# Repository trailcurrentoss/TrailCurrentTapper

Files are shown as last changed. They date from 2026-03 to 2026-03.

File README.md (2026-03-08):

# TrailCurrent Tapper

Eight-button control panel that sends device commands and brightness control over a CAN bus interface with OTA firmware update capability. Part of the [TrailCurrent](https://trailcurrent.com) open-source vehicle platform.

## Hardware Overview

- **Microcontroller:** ESP32 (WROOM32)
- **Function:** Physical button panel for CAN bus device control
- **Key Features:**
  - 8 momentary buttons with LED backlights
  - Short press: toggle device on/off
  - Long press (hold 700ms+): brightness adjustment (0-255)
  - CAN bus communication at 500 kbps
  - Over-the-air (OTA) firmware updates via WiFi
  - LED state feedback from CAN bus
  - FreeCAD enclosure design

## Hardware Requirements

### Components

- **Microcontroller:** ESP32 development board
- **CAN Transceiver:** Vehicle CAN bus interface (TX: GPIO 15, RX: GPIO 13)

### Pin Connections

**Buttons (INPUT_PULLUP):**

| GPIO | Function |
|---|---|
| 34 | Button 1 |
| 25 | Button 2 |
| 27 | Button 3 |
| 12 | Button 4 |
| 16 | Button 5 |
| 22 | Button 6 |
| 21 | Button 7 |
| 18 | Button 8 |

**LED Backlights (OUTPUT):**

| GPIO | Function |
|---|---|
| 32 | LED 1 |
| 33 | LED 2 |
| 26 | LED 3 |
| 14 | LED 4 |
| 4 | LED 5 |
| 23 | LED 6 |
| 19 | LED 7 |
| 17 | LED 8 |

### KiCAD Library Dependencies

This project uses the consolidated [TrailCurrentKiCADLibraries](https://github.com/trailcurrentoss/TrailCurrentKiCADLibraries).

**Setup:**

```bash
# Clone the library
git clone git@github.com:trailcurrentoss/TrailCurrentKiCADLibraries.git

# Set environment variables (add to ~/.bashrc or ~/.zshrc)
export TRAILCURRENT_SYMBOL_DIR="/path/to/TrailCurrentKiCADLibraries/symbols"
export TRAILCURRENT_FOOTPRINT_DIR="/path/to/TrailCurrentKiCADLibraries/footprints"
export TRAILCURRENT_3DMODEL_DIR="/path/to/TrailCurrentKiCADLibraries/3d_models"
```

See [KICAD_ENVIRONMENT_SETUP.md](https://github.com/trailcurrentoss/TrailCurrentKiCADLibraries/blob/main/KICAD_ENVIRONMENT_SETUP.md) in the library repository for detailed setup instructions.

## Opening the Project

1. **Set up environment variables** (see Library Dependencies above)
2. **Open KiCAD:**
   ```bash
   kicad EDA/trailcurrent-tapper.kicad_pro
   ```
3. **Verify libraries load** - All symbol and footprint libraries should resolve without errors
4. **View 3D models** - Open PCB and press `Alt+3` to view the 3D visualization

## Firmware

See `src/` directory for PlatformIO-based firmware.

**Setup:**
```bash
# Install PlatformIO (if not already installed)
pip install platformio

# Build firmware
pio run

# Upload to board (serial)
pio run -t upload

# Upload via OTA (after initial flash)
pio run -t upload --upload-port esp32-DEVICE_ID
```

### Firmware Dependencies

This firmware depends on the following public libraries:

- **[OtaUpdateLibraryWROOM32](https://github.com/trailcurrentoss/OtaUpdateLibraryWROOM32)** (v0.0.1) - Over-the-air firmware update functionality
- **[TwaiTaskBasedLibraryWROOM32](https://github.com/trailcurrentoss/TwaiTaskBasedLibraryWROOM32)** (v0.0.1) - CAN bus communication interface

All dependencies are automatically resolved by PlatformIO during the build process.

### CAN Bus Protocol

**Transmit (Panel to Bus):**

| CAN ID | Bytes | Description |
|---|---|---|
| 0x18 | 1 | Button toggle (byte 0 = button index 0-7) |
| 0x15 | 2 | Brightness control (byte 0 = device index, byte 1 = brightness 0-255) |

**Receive (Bus to Panel):**

| CAN ID | Bytes | Description |
|---|---|---|
| 0x00 | 3 | OTA update trigger (MAC-based device targeting) |
| 0x1B | 8 | LED backlight state (1 byte per LED, 0=off, non-zero=on) |

### Button Behavior

- **Short press** (< 700ms): Sends toggle command on CAN ID 0x18
- **Long hold** (>= 700ms): Enters brightness mode, incrementing brightness every 100ms and sending on CAN ID 0x15
- **Release after hold**: Locks brightness at current value

## Manufacturing

- **PCB Files:** Ready for fabrication via standard PCB services (JLCPCB, OSH Park, etc.)
- **BOM Generation:** Export BOM from KiCAD schematic (Tools > Generate BOM)
- **Enclosure:** FreeCAD design included in `CAD/` directory
- **JLCPCB Assembly:** See [BOM_ASSEMBLY_WORKFLOW.md](https://github.com/trailcurrentoss/TrailCurrentKiCADLibraries/blob/main/BOM_ASSEMBLY_WORKFLOW.md) for detailed assembly workflow

## Project Structure

```
├── CAD/                          # FreeCAD enclosure design
├── EDA/                          # KiCAD hardware design files
│   ├── trailcurrent-tapper.kicad_pro
│   ├── trailcurrent-tapper.kicad_sch
│   └── trailcurrent-tapper.kicad_pcb
├── src/                          # Firmware source
│   ├── main.cpp                  # Button handling and CAN communication
│   ├── globals.h                 # LED pin definitions
│   ├── debug.h                   # Comprehensive debug macro system
│   ├── canHelper.h               # CAN bus configuration
│   └── Secrets.h.template        # WiFi credentials template
├── ARCHITECTURE_CORRECTED.md     # Architecture documentation
├── BUTTON_LED_FIX_SUMMARY.md     # Button/LED fix notes
├── platformio.ini                # Build configuration
└── partitions.csv                # ESP32 flash partition layout
```

## License

MIT License - See LICENSE file for details.

## Contributing

Improvements and contributions are welcome! Please submit issues or pull requests.

## Support

For questions about:
- **KiCAD setup:** See [KICAD_ENVIRONMENT_SETUP.md](https://github.com/trailcurrentoss/TrailCurrentKiCADLibraries/blob/main/KICAD_ENVIRONMENT_SETUP.md)
- **Assembly workflow:** See [BOM_ASSEMBLY_WORKFLOW.md](https://github.com/trailcurrentoss/TrailCurrentKiCADLibraries/blob/main/BOM_ASSEMBLY_WORKFLOW.md)

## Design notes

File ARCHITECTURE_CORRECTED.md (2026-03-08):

# Button/LED Architecture - Corrected

## Understanding the Multi-Panel System

The TrailCurrent Tapper operates in a **coordinated multi-panel environment** where multiple panels share the same CAN bus. Each panel can control lights on other panels, so LED state must be **synchronized via CAN** rather than controlled locally.

---

## Complete Message Flow

### 1️⃣ Button Press Event
```
Physical Button 1 Pressed
        ↓
while button held, every 200ms:
        ↓
send CAN ID 0x18, data[0]=0 (button index 0)
        ↓
Serial output: "[BTN] Button 1 pressed - CAN message sent"
```

### 2️⃣ External Controller Processing
```
Some device on CAN bus receives CAN ID 0x18
        ↓
Decides: "Button 1 pressed, toggle light 1"
        ↓
Updates its light state database
        ↓
Broadcasts new light state via CAN ID 0x1B
```

### 3️⃣ All Panels Update Lights
```
All panels (including this one) receive:
CAN ID 0x1B, data[0-7] = [light1_state, light2_state, ..., light8_state]
        ↓
Each panel updates its LED backlights
        ↓
Serial output: "[LED] Backlight states: 255,0,255,0,255,0,255,0"
```

### 4️⃣ Visual Feedback
```
LED backlights now show the CURRENT state from CAN bus
        ↓
If another panel turned light 1 on, this panel sees it too
        ↓
All panels always agree on the current state
```

---

## CAN Message Protocol

### Button Press Message (ID 0x18)
```
Identifier: 0x18 (24 decimal)
Data Length: 1 byte
Data Format: [button_index]
  - button_index = 0-7 (for buttons 1-8)

Example: Button 3 pressed
  ID: 0x18
  Data: [2]  (index 2 = button 3)
```

### LED State Broadcast (ID 0x1B)
```
Identifier: 0x1B (27 decimal)
Data Length: 8 bytes
Data Format: [led1, led2, led3, led4, led5, led6, led7, led8]
  - led_X = 0x00 (OFF) or 0xFF (ON) or any value > 0

Example: Lights 1, 3, 5, 7 are ON; 2, 4, 6, 8 are OFF
  ID: 0x1B
  Data: [0xFF, 0x00, 0xFF, 0x00, 0xFF, 0x00, 0xFF, 0x00]
```

---

## Code Implementation

### Button Handling (main.cpp loop)
```cpp
// HANDLE BTN01
if (digitalRead(BTN1_PIN) == LOW) {
  if ((millis() - btn01DebounceTime) > debounceDelay) {
    btn01DebounceTime = millis();
    send_message(0);  // Send button 1 (index 0)
  }
}
```
- Checks if button is pressed (LOW)
- Respects 200ms debounce delay
- Sends message every 200ms while button held
- No local LED toggle - just sends button press

### LED Receive (onCanRx callback)
```cpp
else if (msg.identifier == 0x1B) {
  // Expected: 8 bytes of LED data
  if (msg.data_length_code >= 8) {
    // Update LED backlights based on received state
    digitalWrite(LED1_PIN, msg.data[0] > 0 ? HIGH : LOW);
    digitalWrite(LED2_PIN, msg.data[1] > 0 ? HIGH : LOW);
    // ... (all 8 LEDs)
  }
}
```
- Only processes messages with ID 0x1B
- Updates all 8 LED GPIO pins based on received data
- No local state tracking - LEDs mirror CAN bus state

---

## Why This Architecture?

### Problem: Multiple Panels on Same Bus
- Panel A might control light 1
- Panel B might also control light 1
- What's the actual state of light 1?

### Solution: Single Source of Truth
- **The CAN bus is the source of truth**
- One device (or system) decides light states
- All devices receive the same state broadcast
- All devices display the same backlight status
- No conflicts, no confusion

### Benefits
✅ **Synchronized**: All panels always show correct state
✅ **Coordinated**: Multiple panels don't conflict
✅ **Simple**: Buttons just send press events
✅ **Scalable**: Works with any number of panels
✅ **Reliable**: State is explicit, not inferred

---

## Testing the System

### What You Should See

**When Button 1 is Pressed:**
```
[BTN] Button 1 pressed - CAN message sent
```
(Repeats every 200ms while button is held)

**When LED State is Broadcast:**
```
[LED] Backlight states: 255,0,255,0,255,0,255,0
```
(Shows all 8 LED values received from CAN bus)

**Expected Behavior:**
1. Press button 1 → see button message
2. External system (controller) receives it and broadcasts new state
3. This panel receives new LED state and updates backlights
4. All panels update backlights

### If It's Not Working

**Symptoms: Button press but LED doesn't update**
- Issue: Button message being sent but controller not responding
- Check: Is there a device on CAN bus listening to ID 0x18?
- Check: Is that device sending back LED state on ID 0x1B?

**Symptoms: LED updates but wrong lights**
- Issue: CAN message data[X] mapping is wrong
- Check: Verify LED data byte order matches your hardware
- Check: Verify LED GPIO pins are correct

**Symptoms: Multiple lights turning on unexpectedly**
- Issue: Button 1 press was causing multiple buttons to trigger
- Check: GPIO pin definitions (BTN1_PIN, etc.)
- Check: Button INPUT_PULLUP configuration
- Check: Debounce timing

---

## Original vs New Architecture

### Original (Polling-Based)
- Raw TWAI driver in canHelper.h
- CAN polling in main loop (every iteration)
- Synchronous message reception
- Filter: Only accept ID 0x1B messages
- No OTA support

### New (Callback-Based with OTA)
- TwaiTaskBased library (FreeRTOS tasks)
- Asynchronous callbacks for RX/TX
- Tasks handle CAN in background
- Accept-all filter (process all IDs in callbacks)
- OTA support via CAN ID 0x0 trigger
- Variadic debug macros

**The Button/LED logic remains the same**, just using new library:
- Buttons still send ID 0x18
- LEDs still respond to ID 0x1B
- Same message format, same behavior

---

## Multi-Device Example

### Scenario: 2 Panels on Same Bus

```
Panel A (this device):         Panel B (other device):
├─ Button 1                    ├─ Button 1
├─ Button 2                    ├─ Button 2
├─ LED 1-8 backlights          ├─ LED 1-8 backlights
└─ CAN bus                     └─ CAN bus
         │                            │
         └────────────────────────────┘
                (shared CAN)

Scenario: User presses Button 1 on Panel B
1. Panel B sends: CAN ID 0x18, data[0]=0
2. Central controller receives and toggles light 1
3. Controller broadcasts: CAN ID 0x1B, data=[255,0,0,0,0,0,0,0]
4. Panel A receives and updates: LED1=ON, LED2-8=OFF
5. Panel B receives and updates: LED1=ON, LED2-8=OFF
6. Both panels show same state ✅
```

---

## Configuration Reference

### GPIO Pins (globals.h)
```cpp
LED1_PIN = 32,  LED2_PIN = 33,  LED3_PIN = 26,  LED4_PIN = 14
LED5_PIN = 4,   LED6_PIN = 23,  LED7_PIN = 19,  LED8_PIN = 17

BTN1_PIN = 34,  BTN2_PIN = 25,  BTN3_PIN = 27,  BTN4_PIN = 12
BTN5_PIN = 16,  BTN6_PIN = 22,  BTN7_PIN = 21,  BTN8_PIN = 18
```

### CAN Settings (main.cpp)
```cpp
CAN_TX = GPIO 15
CAN_RX = GPIO 13
Baudrate = 500 kbps
Filter = Accept all messages
```

### Debounce Timing (main.cpp)
```cpp
debounceDelay = 200ms  // Minimum time between button messages
```

---

## Summary

**The system works as a coordinated CAN bus network:**
- Buttons send requests (button press events)
- A controller processes requests (toggles lights, makes decisions)
- Controller broadcasts state (all lights current status)
- All panels display state (LED backlights show current state)

**This ensures all panels always agree on the current light state**, regardless of which panel's button was pressed.

**Files Modified:**
- `src/main.cpp` - Simplified button/LED logic to match original architecture
- `src/globals.h` - Cleaned up and organized LED/button pins

**Date Corrected:** 2026-02-10

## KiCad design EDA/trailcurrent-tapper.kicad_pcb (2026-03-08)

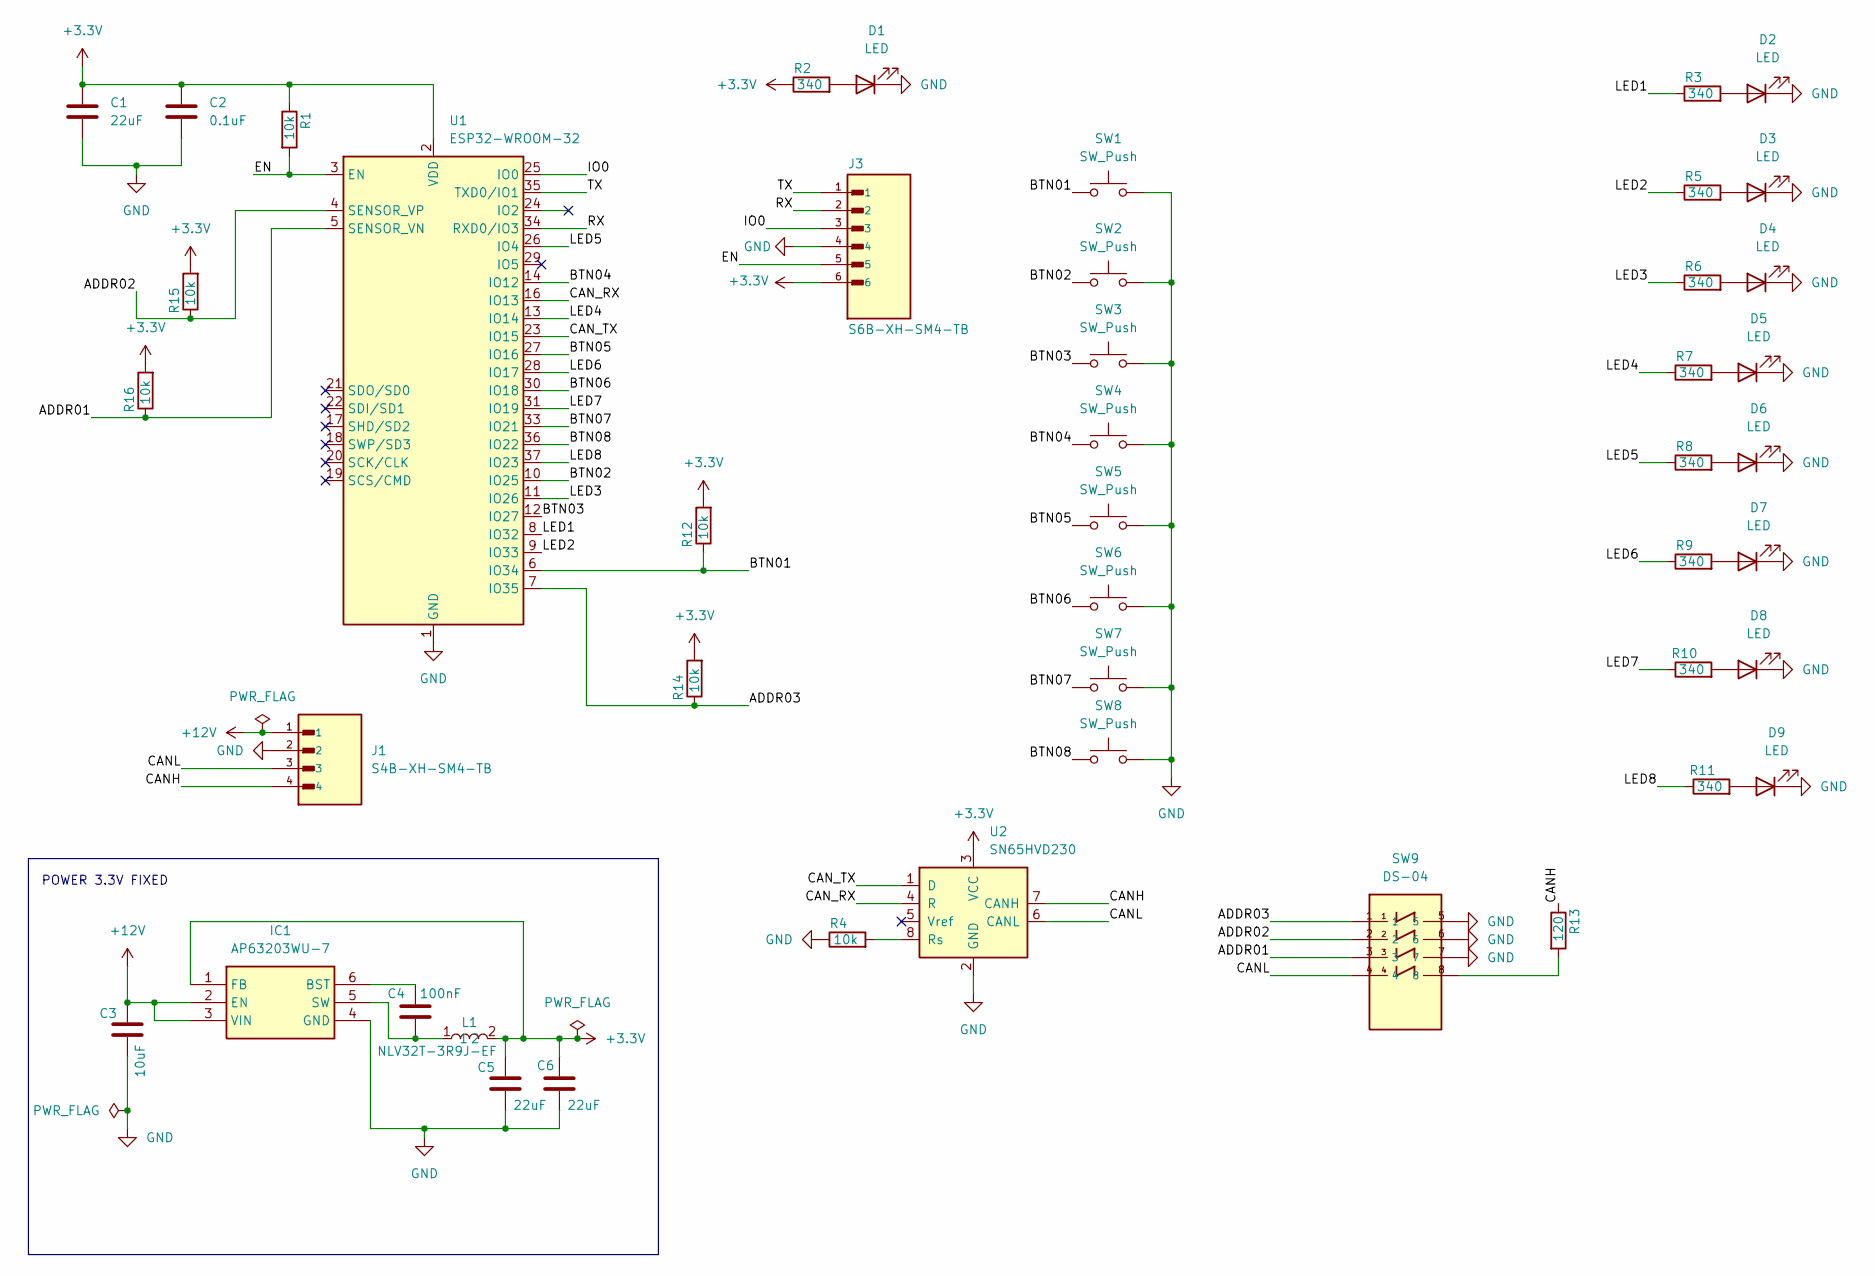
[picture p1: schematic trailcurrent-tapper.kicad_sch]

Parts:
C1, C5, C6: 22uF; C_1206_3216Metric_Pad1.33x1.80mm_HandSolder
C2: 0.1uF; C_1206_3216Metric_Pad1.33x1.80mm_HandSolder
C3: 10uF; C_1206_3216Metric
C4: 100nF; C_1206_3216Metric
D1, D2, D3, D4, D5, D6, D7, D8, D9: LED; LED_1206_3216Metric_Pad1.42x1.75mm_HandSolder
IC1: AP63203WU-7; AP63203WU7; Mouser Part Number 621-AP63203WU-7
J1: S4B-XH-SM4-TB; JST_S4B-XH-SM4-TB; LCSC Part C161861
J3: S6B-XH-SM4-TB; JST_S6B-XH-SM4-TB; LCSC Part C191914
L1: NLV32T-3R9J-EF; Manufacturer_Part_Number NLV32T-3R9J-EF; Mouser Part Number 810-NLV32T3R9JEF
R1, R4, R12, R14, R15, R16: 10k; R_1206_3216Metric_Pad1.30x1.75mm_HandSolder
R2, R3, R5, R6, R7, R8, R9, R10, R11: 340; R_1206_3216Metric_Pad1.30x1.75mm_HandSolder
R13: 120; R_1206_3216Metric_Pad1.30x1.75mm_HandSolder
SW1, SW2, SW3, SW4, SW5, SW6, SW7, SW8: SW_Push; SW_PUSH_6mm
SW9: DS-04; Manufacturer_Part_Number DS-04
U1: ESP32-WROOM-32; ESP32-WROOM-32U
U2: SN65HVD230; SOIC-8_3.9x4.9mm_P1.27mm

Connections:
+3.3V: C1.1, C2.1, C5.1, C6.1, IC1.1 (FB), J3.6, L1.2, R1.1, R2.1, R12.2, R14.2, R15.2, R16.2, U1.2 (VDD), U2.3 (VCC)
+12V: C3.1, IC1.2 (EN), IC1.3 (VIN), J1.1
/ADDR01: R16.1, SW9.3, U1.5 (SENSOR_VN)
/ADDR02: R15.1, SW9.2, U1.4 (SENSOR_VP)
/ADDR03: R14.1, SW9.1, U1.7 (IO35)
/BTN01: R12.1, SW1.1, U1.6 (IO34)
/BTN02: SW2.1, U1.10 (IO25)
/BTN03: SW3.1, U1.12 (IO27)
/BTN04: SW4.1, U1.14 (IO12)
/BTN05: SW5.1, U1.27 (IO16)
/BTN06: SW6.1, U1.30 (IO18)
/BTN07: SW7.1, U1.33 (IO21)
/BTN08: SW8.1, U1.36 (IO22)
/CANH: J1.4, R13.1, U2.7 (CANH)
/CANL: J1.3, SW9.4, U2.6 (CANL)
/CAN_RX: U1.16 (IO13), U2.4 (R)
/CAN_TX: U1.23 (IO15), U2.1 (D)
/EN: J3.5, R1.2, U1.3 (EN)
/IO0: J3.3, U1.25 (IO0)
/LED1: R3.1, U1.8 (IO32)
/LED2: R5.1, U1.9 (IO33)
/LED3: R6.1, U1.11 (IO26)
/LED4: R7.1, U1.13 (IO14)
/LED5: R8.1, U1.26 (IO4)
/LED6: R9.1, U1.28 (IO17)
/LED7: R10.1, U1.31 (IO19)
/LED8: R11.1, U1.37 (IO23)
/RX: J3.2, U1.34 (RXD0/IO3)
/TX: J3.1, U1.35 (TXD0/IO1)
GND: C1.2, C2.2, C3.2, C5.2, C6.2, D1.1 (K), D2.1 (K), D3.1 (K), D4.1 (K), D5.1 (K), D6.1 (K), D7.1 (K), D8.1 (K), D9.1 (K), IC1.4 (GND), J1.2, J3.4, R4.1, SW1.2, SW2.2, SW3.2, SW4.2, SW5.2, SW6.2, SW7.2, SW8.2, SW9.5, SW9.6, SW9.7, U1.1 (GND), U1.15 (GND), U1.38 (GND), U1.39 (GND), U2.2 (GND)
unnamed: D1.2 (A), R2.2
unnamed: D2.2 (A), R3.2
unnamed: D3.2 (A), R5.2
unnamed: D4.2 (A), R6.2
unnamed: D5.2 (A), R7.2
unnamed: D6.2 (A), R8.2
unnamed: D7.2 (A), R9.2
unnamed: D8.2 (A), R10.2
unnamed: D9.2 (A), R11.2
unnamed: C4.1, IC1.6 (BST)
unnamed: C4.2, IC1.5 (SW), L1.1
unnamed: R13.2, SW9.8
unnamed: R4.2, U2.8 (Rs)

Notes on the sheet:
POWER 3.3V FIXED

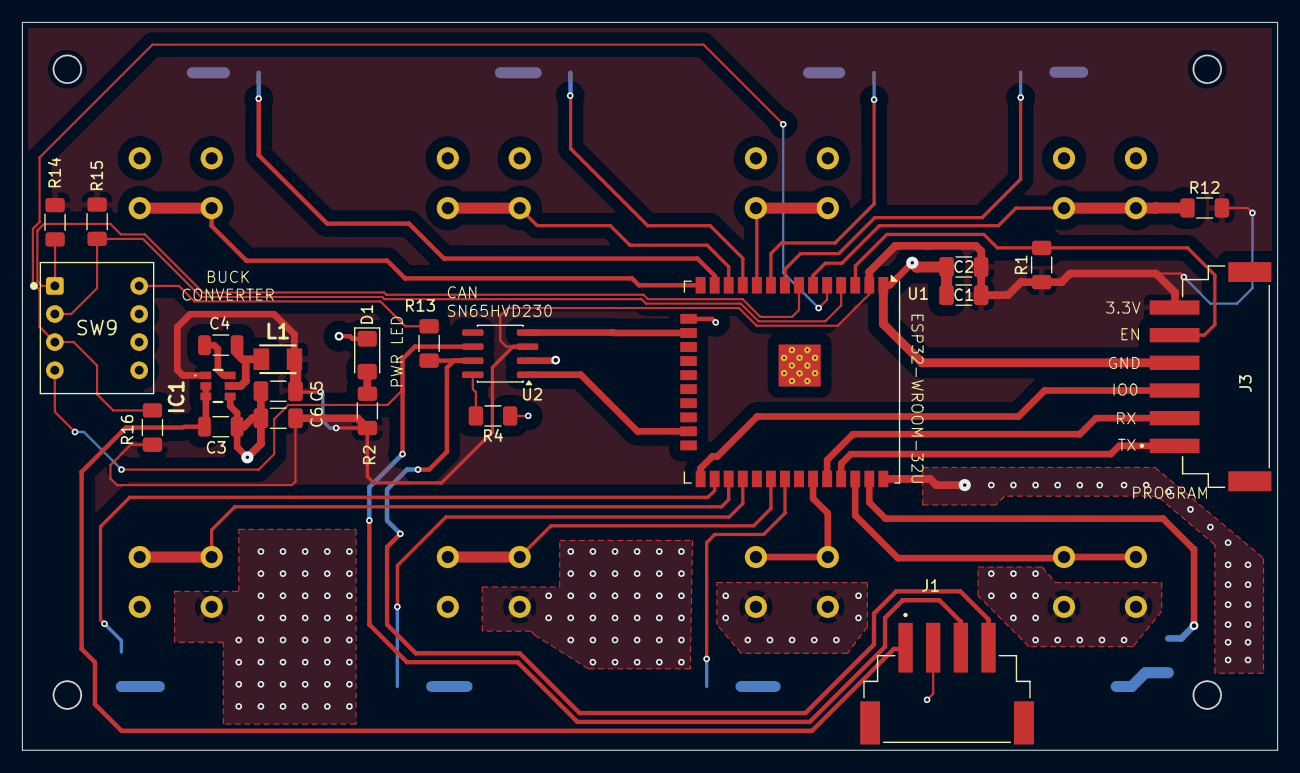
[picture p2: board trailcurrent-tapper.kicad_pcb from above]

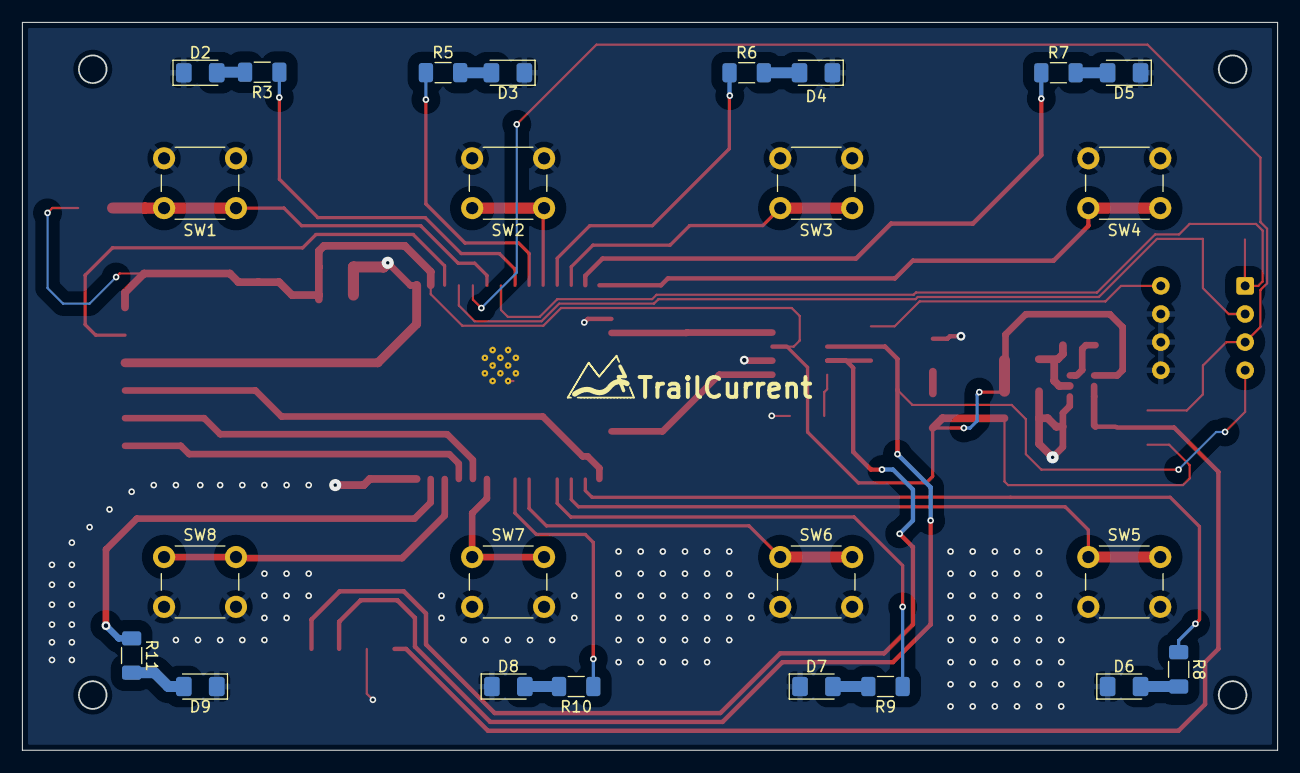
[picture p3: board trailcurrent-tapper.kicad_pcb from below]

Board: 2 copper layers, 113.4 x 65.8 mm, 48 parts (25 on the bottom side), 43 nets.

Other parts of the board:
LOGO: TrailCurrentLogo_Text
LOGO#2: TrailCurrentLogo_Icon

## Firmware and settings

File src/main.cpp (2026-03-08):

#include <Arduino.h>
#include <stdint.h>
#include <Preferences.h>
#include <TwaiTaskBased.h>
#include <OtaUpdate.h>
#include "globals.h"

// Button debounce timing
unsigned long btn01DebounceTime = 0;
unsigned long btn02DebounceTime = 0;
unsigned long btn03DebounceTime = 0;
unsigned long btn04DebounceTime = 0;
unsigned long btn05DebounceTime = 0;
unsigned long btn06DebounceTime = 0;
unsigned long btn07DebounceTime = 0;
unsigned long btn08DebounceTime = 0;
unsigned long debounceDelay = 200;

// Button state tracking for press-and-hold brightness control
unsigned long btn01PressStartTime = 0;
unsigned long btn02PressStartTime = 0;
unsigned long btn03PressStartTime = 0;
unsigned long btn04PressStartTime = 0;
unsigned long btn05PressStartTime = 0;
unsigned long btn06PressStartTime = 0;
unsigned long btn07PressStartTime = 0;
unsigned long btn08PressStartTime = 0;

bool btn01WasPressed = false;
bool btn02WasPressed = false;
bool btn03WasPressed = false;
bool btn04WasPressed = false;
bool btn05WasPressed = false;
bool btn06WasPressed = false;
bool btn07WasPressed = false;
bool btn08WasPressed = false;

bool btn01ToggleSent = false;
bool btn02ToggleSent = false;
bool btn03ToggleSent = false;
bool btn04ToggleSent = false;
bool btn05ToggleSent = false;
bool btn06ToggleSent = false;
bool btn07ToggleSent = false;
bool btn08ToggleSent = false;

bool btn01InBrightnessMode = false;
bool btn02InBrightnessMode = false;
bool btn03InBrightnessMode = false;
bool btn04InBrightnessMode = false;
bool btn05InBrightnessMode = false;
bool btn06InBrightnessMode = false;
bool btn07InBrightnessMode = false;
bool btn08InBrightnessMode = false;

uint8_t btn01Brightness = 0;
uint8_t btn02Brightness = 0;
uint8_t btn03Brightness = 0;
uint8_t btn04Brightness = 0;
uint8_t btn05Brightness = 0;
uint8_t btn06Brightness = 0;
uint8_t btn07Brightness = 0;
uint8_t btn08Brightness = 0;

unsigned long btn01LastBrightnessUpdate = 0;
unsigned long btn02LastBrightnessUpdate = 0;
unsigned long btn03LastBrightnessUpdate = 0;
unsigned long btn04LastBrightnessUpdate = 0;
unsigned long btn05LastBrightnessUpdate = 0;
unsigned long btn06LastBrightnessUpdate = 0;
unsigned long btn07LastBrightnessUpdate = 0;
unsigned long btn08LastBrightnessUpdate = 0;

// Timing constants for brightness control
const unsigned long HOLD_THRESHOLD = 700;        // 700ms to enter brightness mode
const unsigned long BRIGHTNESS_INCREMENT = 100;  // Update brightness every 100ms

// Button GPIO pins
#define BTN1_PIN 34
#define BTN2_PIN 25
#define BTN3_PIN 27
#define BTN4_PIN 12
#define BTN5_PIN 16
#define BTN6_PIN 22
#define BTN7_PIN 21
#define BTN8_PIN 18

// WiFi credential reception state (CAN ID 0x01 protocol)
bool wifiConfigInProgress = false;
uint8_t wifiSsidBuffer[33];       // Max 32 chars + null
uint8_t wifiPasswordBuffer[64];   // Max 63 chars + null
uint8_t wifiSsidLen = 0;          // Expected total SSID length
uint8_t wifiPasswordLen = 0;      // Expected total password length
uint8_t wifiSsidReceived = 0;     // Bytes received so far
uint8_t wifiPasswordReceived = 0;

// Create OTA update handler (3-minute timeout, 180000 ms)
// Credentials are loaded from NVS when OTA is triggered; empty here for getHostName() only
OtaUpdate otaUpdate(180000, "", "");

/**
 * Save WiFi credentials to NVS (Non-Volatile Storage)
 */
void saveWifiCredentials(const char* ssid, const char* password) {
  Preferences prefs;
  prefs.begin("wifi", false);  // read-write
  prefs.putString("ssid", ssid);
  prefs.putString("password", password);
  prefs.end();
  debugf("[WiFi] Credentials saved to NVS (SSID: %s)\n", ssid);
}

/**
 * Handle WiFi credential CAN messages (CAN ID 0x01)
 * Protocol uses data[0] as message type:
 *   0x01: Start - contains SSID/password lengths and chunk counts
 *   0x02: SSID chunk - chunk_index + up to 6 data bytes
 *   0x03: Password chunk - chunk_index + up to 6 data bytes
 *   0x04: End - XOR checksum for validation
 */
void handleWifiConfigMessage(const twai_message_t &msg) {
  uint8_t msgType = msg.data[0];

  switch (msgType) {
    case 0x01: {  // Start message
      wifiSsidLen = msg.data[1];
      wifiPasswordLen = msg.data[2];
      wifiSsidReceived = 0;
      wifiPasswordReceived = 0;
      memset(wifiSsidBuffer, 0, sizeof(wifiSsidBuffer));
      memset(wifiPasswordBuffer, 0, sizeof(wifiPasswordBuffer));
      wifiConfigInProgress = true;
      debugf("[WiFi] Config start: SSID len=%d, Password len=%d\n", wifiSsidLen, wifiPasswordLen);
      break;
    }

    case 0x02: {  // SSID chunk
      if (!wifiConfigInProgress) break;
      uint8_t dataBytes = msg.data_length_code - 2;
      uint8_t remaining = wifiSsidLen - wifiSsidReceived;
      if (dataBytes > remaining) dataBytes = remaining;
      if (wifiSsidReceived + dataBytes <= 32) {
        memcpy(wifiSsidBuffer + wifiSsidReceived, &msg.data[2], dataBytes);
        wifiSsidReceived += dataBytes;
      }
      break;
    }

    case 0x03: {  // Password chunk
      if (!wifiConfigInProgress) break;
      uint8_t dataBytes = msg.data_length_code - 2;
      uint8_t remaining = wifiPasswordLen - wifiPasswordReceived;
      if (dataBytes > remaining) dataBytes = remaining;
      if (wifiPasswordReceived + dataBytes <= 63) {
        memcpy(wifiPasswordBuffer + wifiPasswordReceived, &msg.data[2], dataBytes);
        wifiPasswordReceived += dataBytes;
      }
      break;
    }

    case 0x04: {  // End message with checksum
      if (!wifiConfigInProgress) break;
      wifiConfigInProgress = false;

      // Verify XOR checksum
      uint8_t checksum = 0;
      for (uint8_t i = 0; i < wifiSsidReceived; i++) checksum ^= wifiSsidBuffer[i];
      for (uint8_t i = 0; i < wifiPasswordReceived; i++) checksum ^= wifiPasswordBuffer[i];

      if (checksum == msg.data[1] && wifiSsidReceived == wifiSsidLen && wifiPasswordReceived == wifiPasswordLen) {
        wifiSsidBuffer[wifiSsidReceived] = '\0';
        wifiPasswordBuffer[wifiPasswordReceived] = '\0';
        saveWifiCredentials((const char*)wifiSsidBuffer, (const char*)wifiPasswordBuffer);
      } else {
        debugf("[WiFi] Config failed: checksum %s, SSID %d/%d bytes, Password %d/%d bytes\n",
               (checksum == msg.data[1]) ? "OK" : "MISMATCH",
               wifiSsidReceived, wifiSsidLen, wifiPasswordReceived, wifiPasswordLen);
      }
      break;
    }
  }
}

/**
 * CAN RX Callback - called when a CAN message is received
 * Handles three types of messages:
 *   - ID 0x0: OTA trigger (MAC-based targeting)
 *   - ID 0x01: WiFi credential configuration
 *   - ID 0x1B: LED control commands
 */
void onCanRx(const twai_message_t &msg) {
  // OTA trigger message (ID 0x0)
  if (msg.identifier == 0x0) {
    debugln("[OTA] CAN trigger received");

    // Extract target hostname from CAN data
    char updateForHostName[14];
    String currentHostName = otaUpdate.getHostName();

    // Format: esp32-XXXXXX where X is MAC address in hex
    sprintf(updateForHostName, "esp32-%02X%02X%02X",
            msg.data[0], msg.data[1], msg.data[2]);

    debugf("[OTA] Target hostname: %s\n", updateForHostName);
    debugf("[OTA] Current hostname: %s\n", currentHostName.c_str());

    // Check if this OTA trigger is for this device
    if (currentHostName.equals(updateForHostName)) {
      debugln("[OTA] Hostname matched - reading WiFi credentials from NVS");
      Preferences prefs;
      prefs.begin("wifi", true);  // read-only
      String ssid = prefs.getString("ssid", "");
      String password = prefs.getString("password", "");
      prefs.end();

      if (ssid.length() > 0 && password.length() > 0) {
        debugf("[OTA] Using stored WiFi credentials (SSID: %s)\n", ssid.c_str());
        OtaUpdate ota(180000, ssid.c_str(), password.c_str());
        ota.waitForOta();
        debugln("[OTA] OTA mode exited - resuming normal operation");
      } else {
        debugln("[OTA] ERROR: No WiFi credentials in NVS - cannot start OTA");
      }
    }
  }

  // WiFi credential configuration message (ID 0x01)
  else if (msg.identifier == 0x01) {
    handleWifiConfigMessage(msg);
  }

  // LED control message (ID 0x1B) - updates LED backlights to show current state
  else if (msg.identifier == 0x1B) {
    // Expected: 8 bytes of LED data (0 = OFF, non-zero = ON)
    if (msg.data_length_code >= 8) {
      debugln("[LED] LED state update received");

      // Update LED backlights based on received state
      digitalWrite(LED1_PIN, msg.data[0] > 0 ? HIGH : LOW);
      digitalWrite(LED2_PIN, msg.data[1] > 0 ? HIGH : LOW);
      digitalWrite(LED3_PIN, msg.data[2] > 0 ? HIGH : LOW);
      digitalWrite(LED4_PIN, msg.data[3] > 0 ? HIGH : LOW);
      digitalWrite(LED5_PIN, msg.data[4] > 0 ? HIGH : LOW);
      digitalWrite(LED6_PIN, msg.data[5] > 0 ? HIGH : LOW);
      digitalWrite(LED7_PIN, msg.data[6] > 0 ? HIGH : LOW);
      digitalWrite(LED8_PIN, msg.data[7] > 0 ? HIGH : LOW);

      debugf("[LED] Backlight states: %d,%d,%d,%d,%d,%d,%d,%d\n",
             msg.data[0], msg.data[1], msg.data[2], msg.data[3],
             msg.data[4], msg.data[5], msg.data[6], msg.data[7]);
    }
  }
}

/**
 * CAN TX Callback - called when a CAN message transmission completes
 * Logs transmission result
 */
void onCanTx(bool success) {
  if (!success) {
    debugln("[CAN] Transmission failed");
  }
}

/**
 * Send a CAN button message
 * Message format: ID=0x18, 1 byte containing button index (0-7)
 * The external controller receives this and toggles the light state,
 * then broadcasts the new state via CAN ID 0x1B for all panels to display
 */
void send_message(int buttonIndex) {
  twai_message_t message;
  message.identifier = 0x18;           // Button press message ID
  message.extd = false;                // Standard CAN format
  message.rtr = false;
  message.data_length_code = 1;
  message.data[0] = buttonIndex;       // Button index (0-7)

  if (TwaiTaskBased::send(message)) {
    debugf("[BTN] Button %d pressed - CAN message sent\n", buttonIndex + 1);
  } else {
    debugf("[BTN] Button %d pressed - CAN TX failed\n", buttonIndex + 1);
  }
}

/**
 * Send a CAN brightness control message
 * Message format: ID=0x015, 2 bytes [device_index, brightness]
 * Button N controls device N brightness on the CAN bus
 */
void send_brightness_message(int deviceIndex, uint8_t brightness) {
  twai_message_t message;
  message.identifier = 0x015;          // Brightness control message ID
  message.extd = false;                // Standard CAN format
  message.rtr = false;
  message.data_length_code = 2;
  message.data[0] = deviceIndex;       // Device index (0-7)
  message.data[1] = brightness;        // Brightness (0-255)

  if (TwaiTaskBased::send(message)) {
    debugf("[BTN] Device %d brightness set to %d\n", deviceIndex + 1, brightness);
  } else {
    debugf("[BTN] Device %d brightness message failed\n", deviceIndex + 1);
  }
}

void setup() {
  Serial.begin(115200);
  delay(100);

  debugln("=== TrailCurrent Tapper ===");
  debugln("CAN Bus Control with OTA Updates");

  // Initialize LED pins (outputs)
  pinMode(LED1_PIN, OUTPUT);
  pinMode(LED2_PIN, OUTPUT);
  pinMode(LED3_PIN, OUTPUT);
  pinMode(LED4_PIN, OUTPUT);
  pinMode(LED5_PIN, OUTPUT);
  pinMode(LED6_PIN, OUTPUT);
  pinMode(LED7_PIN, OUTPUT);
  pinMode(LED8_PIN, OUTPUT);

  // Turn off all LEDs initially
  digitalWrite(LED1_PIN, LOW);
  digitalWrite(LED2_PIN, LOW);
  digitalWrite(LED3_PIN, LOW);
  digitalWrite(LED4_PIN, LOW);
  digitalWrite(LED5_PIN, LOW);
  digitalWrite(LED6_PIN, LOW);
  digitalWrite(LED7_PIN, LOW);
  digitalWrite(LED8_PIN, LOW);

  debugln("[LED] All LEDs initialized to OFF");

  // Initialize button pins (inputs with pullup)
  pinMode(BTN1_PIN, INPUT_PULLUP);
  pinMode(BTN2_PIN, INPUT_PULLUP);
  pinMode(BTN3_PIN, INPUT_PULLUP);
  pinMode(BTN4_PIN, INPUT_PULLUP);
  pinMode(BTN5_PIN, INPUT_PULLUP);
  pinMode(BTN6_PIN, INPUT_PULLUP);
  pinMode(BTN7_PIN, INPUT_PULLUP);
  pinMode(BTN8_PIN, INPUT_PULLUP);

  debugln("[BTN] All buttons initialized");

  // Register CAN callbacks
  TwaiTaskBased::onReceive(onCanRx);
  TwaiTaskBased::onTransmit(onCanTx);

  // Initialize CAN bus
  // GPIO 15 = TX, GPIO 13 = RX, 500 kbps
  if (!TwaiTaskBased::begin(GPIO_NUM_15, GPIO_NUM_13, 500000)) {
    debugln("[CAN] ERROR: Failed to initialize CAN bus!");
    while (1) {  // Halt on CAN initialization failure
      delay(1000);
    }
  }

  debugln("[CAN] CAN bus initialized successfully");
  debugf("[OTA] Device hostname: %s\n", otaUpdate.getHostName().c_str());
  debugln("[OTA] Ready to receive OTA trigger (CAN ID 0x0)");
  debugln("======================================");
  debugln("Normal operation started");
}

void loop() {
  // HANDLE BTN01 - Short press = toggle, Long hold = brightness
  if (digitalRead(BTN1_PIN) == LOW) {
    // Button is pressed
    if (!btn01WasPressed) {
      // Button just pressed (first detection)
      btn01WasPressed = true;
      btn01PressStartTime = millis();
      btn01ToggleSent = false;
      btn01InBrightnessMode = false;
      debugln("[BTN] Button 1 pressed");
    } else {
      // Button is being held
      unsigned long holdDuration = millis() - btn01PressStartTime;

      // Send toggle message on first press (after debounce), before brightness mode
      if (!btn01ToggleSent && !btn01InBrightnessMode && holdDuration >= debounceDelay && holdDuration < HOLD_THRESHOLD) {
        btn01ToggleSent = true;
        debugln("[BTN] Button 1 short press - sending toggle");
        send_message(0);
      }

      // Enter brightness adjustment mode after 700ms
      if (holdDuration >= HOLD_THRESHOLD && !btn01InBrightnessMode) {
        btn01InBrightnessMode = true;
        btn01Brightness = 0;
        btn01LastBrightnessUpdate = millis();
        btn01ToggleSent = false;  // Reset toggle flag when entering brightness
        debugln("[BTN] Button 1 entering brightness mode");
      }

      if (btn01InBrightnessMode) {
        // Brightness adjustment mode - increment every 100ms
        if ((millis() - btn01LastBrightnessUpdate) >= BRIGHTNESS_INCREMENT) {
          btn01LastBrightnessUpdate = millis();
          // Increment brightness and loop: 0 → 1 → ... → 255 → 0
          if (btn01Brightness >= 255) {
            btn01Brightness = 0;
          } else {
            btn01Brightness++;
          }
          send_brightness_message(0, btn01Brightness);
        }
      }
    }
  } else {
    // Button is not pressed (released or never pressed)
    if (btn01WasPressed) {
      // Button was just released
      if (btn01InBrightnessMode) {
        // Long press released - brightness mode ended
        debugf("[BTN] Button 1 brightness mode ended at %d\n", btn01Brightness);
      }

      // Reset state
      btn01WasPressed = false;
      btn01ToggleSent = false;
      btn01InBrightnessMode = false;
    }
  }

  // HANDLE BTN02 - Short press = toggle, Long hold = brightness
  if (digitalRead(BTN2_PIN) == LOW) {
    if (!btn02WasPressed) {
      btn02WasPressed = true;
      btn02PressStartTime = millis();
      btn02ToggleSent = false;
      btn02InBrightnessMode = false;
      debugln("[BTN] Button 2 pressed");
    } else {
      unsigned long holdDuration = millis() - btn02PressStartTime;

      if (!btn02ToggleSent && !btn02InBrightnessMode && holdDuration >= debounceDelay && holdDuration < HOLD_THRESHOLD) {
        btn02ToggleSent = true;
        debugln("[BTN] Button 2 short press - sending toggle");
        send_message(1);
      }

      if (holdDuration >= HOLD_THRESHOLD && !btn02InBrightnessMode) {
        btn02InBrightnessMode = true;
        btn02Brightness = 0;
        btn02LastBrightnessUpdate = millis();
        btn02ToggleSent = false;
        debugln("[BTN] Button 2 entering brightness mode");
      }

      if (btn02InBrightnessMode) {
        if ((millis() - btn02LastBrightnessUpdate) >= BRIGHTNESS_INCREMENT) {
          btn02LastBrightnessUpdate = millis();
          // Increment brightness and loop: 0 → 1 → ... → 255 → 0
          if (btn02Brightness >= 255) {
            btn02Brightness = 0;
          } else {
            btn02Brightness++;
          }
          send_brightness_message(1, btn02Brightness);
        }
      }
    }
  } else {
    if (btn02WasPressed) {
      if (btn02InBrightnessMode) {
        debugf("[BTN] Button 2 brightness mode ended at %d\n", btn02Brightness);
      }

      btn02WasPressed = false;
      btn02ToggleSent = false;
      btn02InBrightnessMode = false;
    }
  }

  // HANDLE BTN03 - Short press = toggle, Long hold = brightness
  if (digitalRead(BTN3_PIN) == LOW) {
    if (!btn03WasPressed) {
      btn03WasPressed = true;
      btn03PressStartTime = millis();
      btn03ToggleSent = false;
      btn03InBrightnessMode = false;
      debugln("[BTN] Button 3 pressed");
    } else {
      unsigned long holdDuration = millis() - btn03PressStartTime;

      if (!btn03ToggleSent && !btn03InBrightnessMode && holdDuration >= debounceDelay && holdDuration < HOLD_THRESHOLD) {
        btn03ToggleSent = true;
        debugln("[BTN] Button 3 short press - sending toggle");
        send_message(2);
      }

      if (holdDuration >= HOLD_THRESHOLD && !btn03InBrightnessMode) {
        btn03InBrightnessMode = true;
        btn03Brightness = 0;
        btn03LastBrightnessUpdate = millis();
        btn03ToggleSent = false;
        debugln("[BTN] Button 3 entering brightness mode");
      }

      if (btn03InBrightnessMode) {
        if ((millis() - btn03LastBrightnessUpdate) >= BRIGHTNESS_INCREMENT) {
          btn03LastBrightnessUpdate = millis();
          // Increment brightness and loop: 0 → 1 → ... → 255 → 0
          if (btn03Brightness >= 255) {
            btn03Brightness = 0;
          } else {
            btn03Brightness++;
          }
          send_brightness_message(2, btn03Brightness);
        }
      }
    }
  } else {
    if (btn03WasPressed) {
      if (btn03InBrightnessMode) {
        debugf("[BTN] Button 3 brightness mode ended at %d\n", btn03Brightness);
      }

      btn03WasPressed = false;
      btn03ToggleSent = false;
      btn03InBrightnessMode = false;
    }
  }

  // HANDLE BTN04 - Short press = toggle, Long hold = brightness
  if (digitalRead(BTN4_PIN) == LOW) {
    if (!btn04WasPressed) {
      btn04WasPressed = true;
      btn04PressStartTime = millis();
      btn04ToggleSent = false;
      btn04InBrightnessMode = false;
      debugln("[BTN] Button 4 pressed");
    } else {
      unsigned long holdDuration = millis() - btn04PressStartTime;

      if (!btn04ToggleSent && !btn04InBrightnessMode && holdDuration >= debounceDelay && holdDuration < HOLD_THRESHOLD) {
        btn04ToggleSent = true;
        debugln("[BTN] Button 4 short press - sending toggle");
        send_message(3);
      }

      if (holdDuration >= HOLD_THRESHOLD && !btn04InBrightnessMode) {
        btn04InBrightnessMode = true;
        btn04Brightness = 0;
        btn04LastBrightnessUpdate = millis();
        btn04ToggleSent = false;
        debugln("[BTN] Button 4 entering brightness mode");
      }

      if (btn04InBrightnessMode) {
        if ((millis() - btn04LastBrightnessUpdate) >= BRIGHTNESS_INCREMENT) {
          btn04LastBrightnessUpdate = millis();
          // Increment brightness and loop: 0 → 1 → ... → 255 → 0
          if (btn04Brightness >= 255) {
            btn04Brightness = 0;
          } else {
            btn04Brightness++;
          }
          send_brightness_message(3, btn04Brightness);
        }
      }
    }
  } else {
    if (btn04WasPressed) {
      if (btn04InBrightnessMode) {
        debugf("[BTN] Button 4 brightness mode ended at %d\n", btn04Brightness);
      }

      btn04WasPressed = false;
      btn04ToggleSent = false;
      btn04InBrightnessMode = false;
    }
  }

  // HANDLE BTN05 - Short press = toggle, Long hold = brightness
  if (digitalRead(BTN5_PIN) == LOW) {
    if (!btn05WasPressed) {
      btn05WasPressed = true;
      btn05PressStartTime = millis();
      btn05ToggleSent = false;
      btn05InBrightnessMode = false;
      debugln("[BTN] Button 5 pressed");
    } else {
      unsigned long holdDuration = millis() - btn05PressStartTime;

      if (!btn05ToggleSent && !btn05InBrightnessMode && holdDuration >= debounceDelay && holdDuration < HOLD_THRESHOLD) {
        btn05ToggleSent = true;
        debugln("[BTN] Button 5 short press - sending toggle");
        send_message(4);
      }

      if (holdDuration >= HOLD_THRESHOLD && !btn05InBrightnessMode) {
        btn05InBrightnessMode = true;
        btn05Brightness = 0;
        btn05LastBrightnessUpdate = millis();
        btn05ToggleSent = false;
        debugln("[BTN] Button 5 entering brightness mode");
      }

      if (btn05InBrightnessMode) {
        if ((millis() - btn05LastBrightnessUpdate) >= BRIGHTNESS_INCREMENT) {
          btn05LastBrightnessUpdate = millis();
          // Increment brightness and loop: 0 → 1 → ... → 255 → 0
          if (btn05Brightness >= 255) {
            btn05Brightness = 0;
          } else {
            btn05Brightness++;
          }
          send_brightness_message(4, btn05Brightness);
        }
      }
    }
  } else {
    if (btn05WasPressed) {
      if (btn05InBrightnessMode) {
        debugf("[BTN] Button 5 brightness mode ended at %d\n", btn05Brightness);
      }

      btn05WasPressed = false;
      btn05ToggleSent = false;
      btn05InBrightnessMode = false;
    }
  }

  // HANDLE BTN06 - Short press = toggle, Long hold = brightness
  if (digitalRead(BTN6_PIN) == LOW) {
    if (!btn06WasPressed) {
      btn06WasPressed = true;
      btn06PressStartTime = millis();
      btn06ToggleSent = false;
      btn06InBrightnessMode = false;
      debugln("[BTN] Button 6 pressed");
    } else {
      unsigned long holdDuration = millis() - btn06PressStartTime;

      if (!btn06ToggleSent && !btn06InBrightnessMode && holdDuration >= debounceDelay && holdDuration < HOLD_THRESHOLD) {
        btn06ToggleSent = true;
        debugln("[BTN] Button 6 short press - sending toggle");
        send_message(5);
      }
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

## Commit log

2026-02-28 Updated PCB to use JST XH connectors
    [trailer-switch-panel-eight-buttons-B_Cu.gbr, trailer-switch-panel-eight-buttons-B_Mask.gbr, trailer-switch-panel-eight-buttons-B_Paste.gbr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]
2026-02-28 Added DIP switch for CAN Termination and device ID settings
    [trailer-switch-panel-eight-buttons.kicad_pcb, trailer-switch-panel-eight-buttons.kicad_sch]
2026-03-08 Aligning with new product names
    [trailcurrent-tapper.kicad_pcb, trailcurrent-tapper.kicad_sch]
2026-03-08 Aligning with product names
    [trailcurrent-tapper.kicad_pcb, trailcurrent-tapper.kicad_sch]
